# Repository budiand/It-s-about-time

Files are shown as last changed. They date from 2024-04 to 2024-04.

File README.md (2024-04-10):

# Proiect - It's about time!

## Realizare schematic:

Cu ajutorul fișierului [hector_watch.pdf](https://ocw.cs.pub.ro/courses/_media/tsc/hector_watch.pdf) ce conține indicații, a fost realizat schematic-ul. Deoarece butoanele și conectorul LCD din biblioteca de mai sus nu respectă anumite criterii, a fost necesară desenarea footprint-urilor acestora și atașarea într-o nouă bibliotecă. Corectitudinea a fost verificată folosind ERC.

## Realizare board:

Primul pas a fost decuparea PCB-ului, astfel încât acesta să respecte indicațiile de măsură (diam = 36mm). Primele componente așezate pe board au fost modulul ESP, conectorul USB C și butoanele, deoarece acestea sunt cele mai restrictive. Așezarea celorlalte componente s-a realizat ținând cont de numărul de semnale din circuit, astfel că numărul cel mai mare de semnale a avut prioritate. Traseele au fost rutate astfel încât să se respecte anumite constrângeri și reguli de "good practice" precum: evitarea intersectării traseelor, evitarea unghiurilor drepte, și altele. În final a fost realizată verificarea DRC cu succes.

## Probleme întâmpinate:

- Din cauza numărului mare de componente și a spațiului restrâns, au fost necesare mai multe încercări pentru a realiza o așezare optimă a componentelor.
- Realizarea footprint-urilor pentru butoane și pentru conectorul LCD a fost dificilă, deoarece a necesitat măsurători precise și ajustări.

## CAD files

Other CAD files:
Hector_Watch.f3z

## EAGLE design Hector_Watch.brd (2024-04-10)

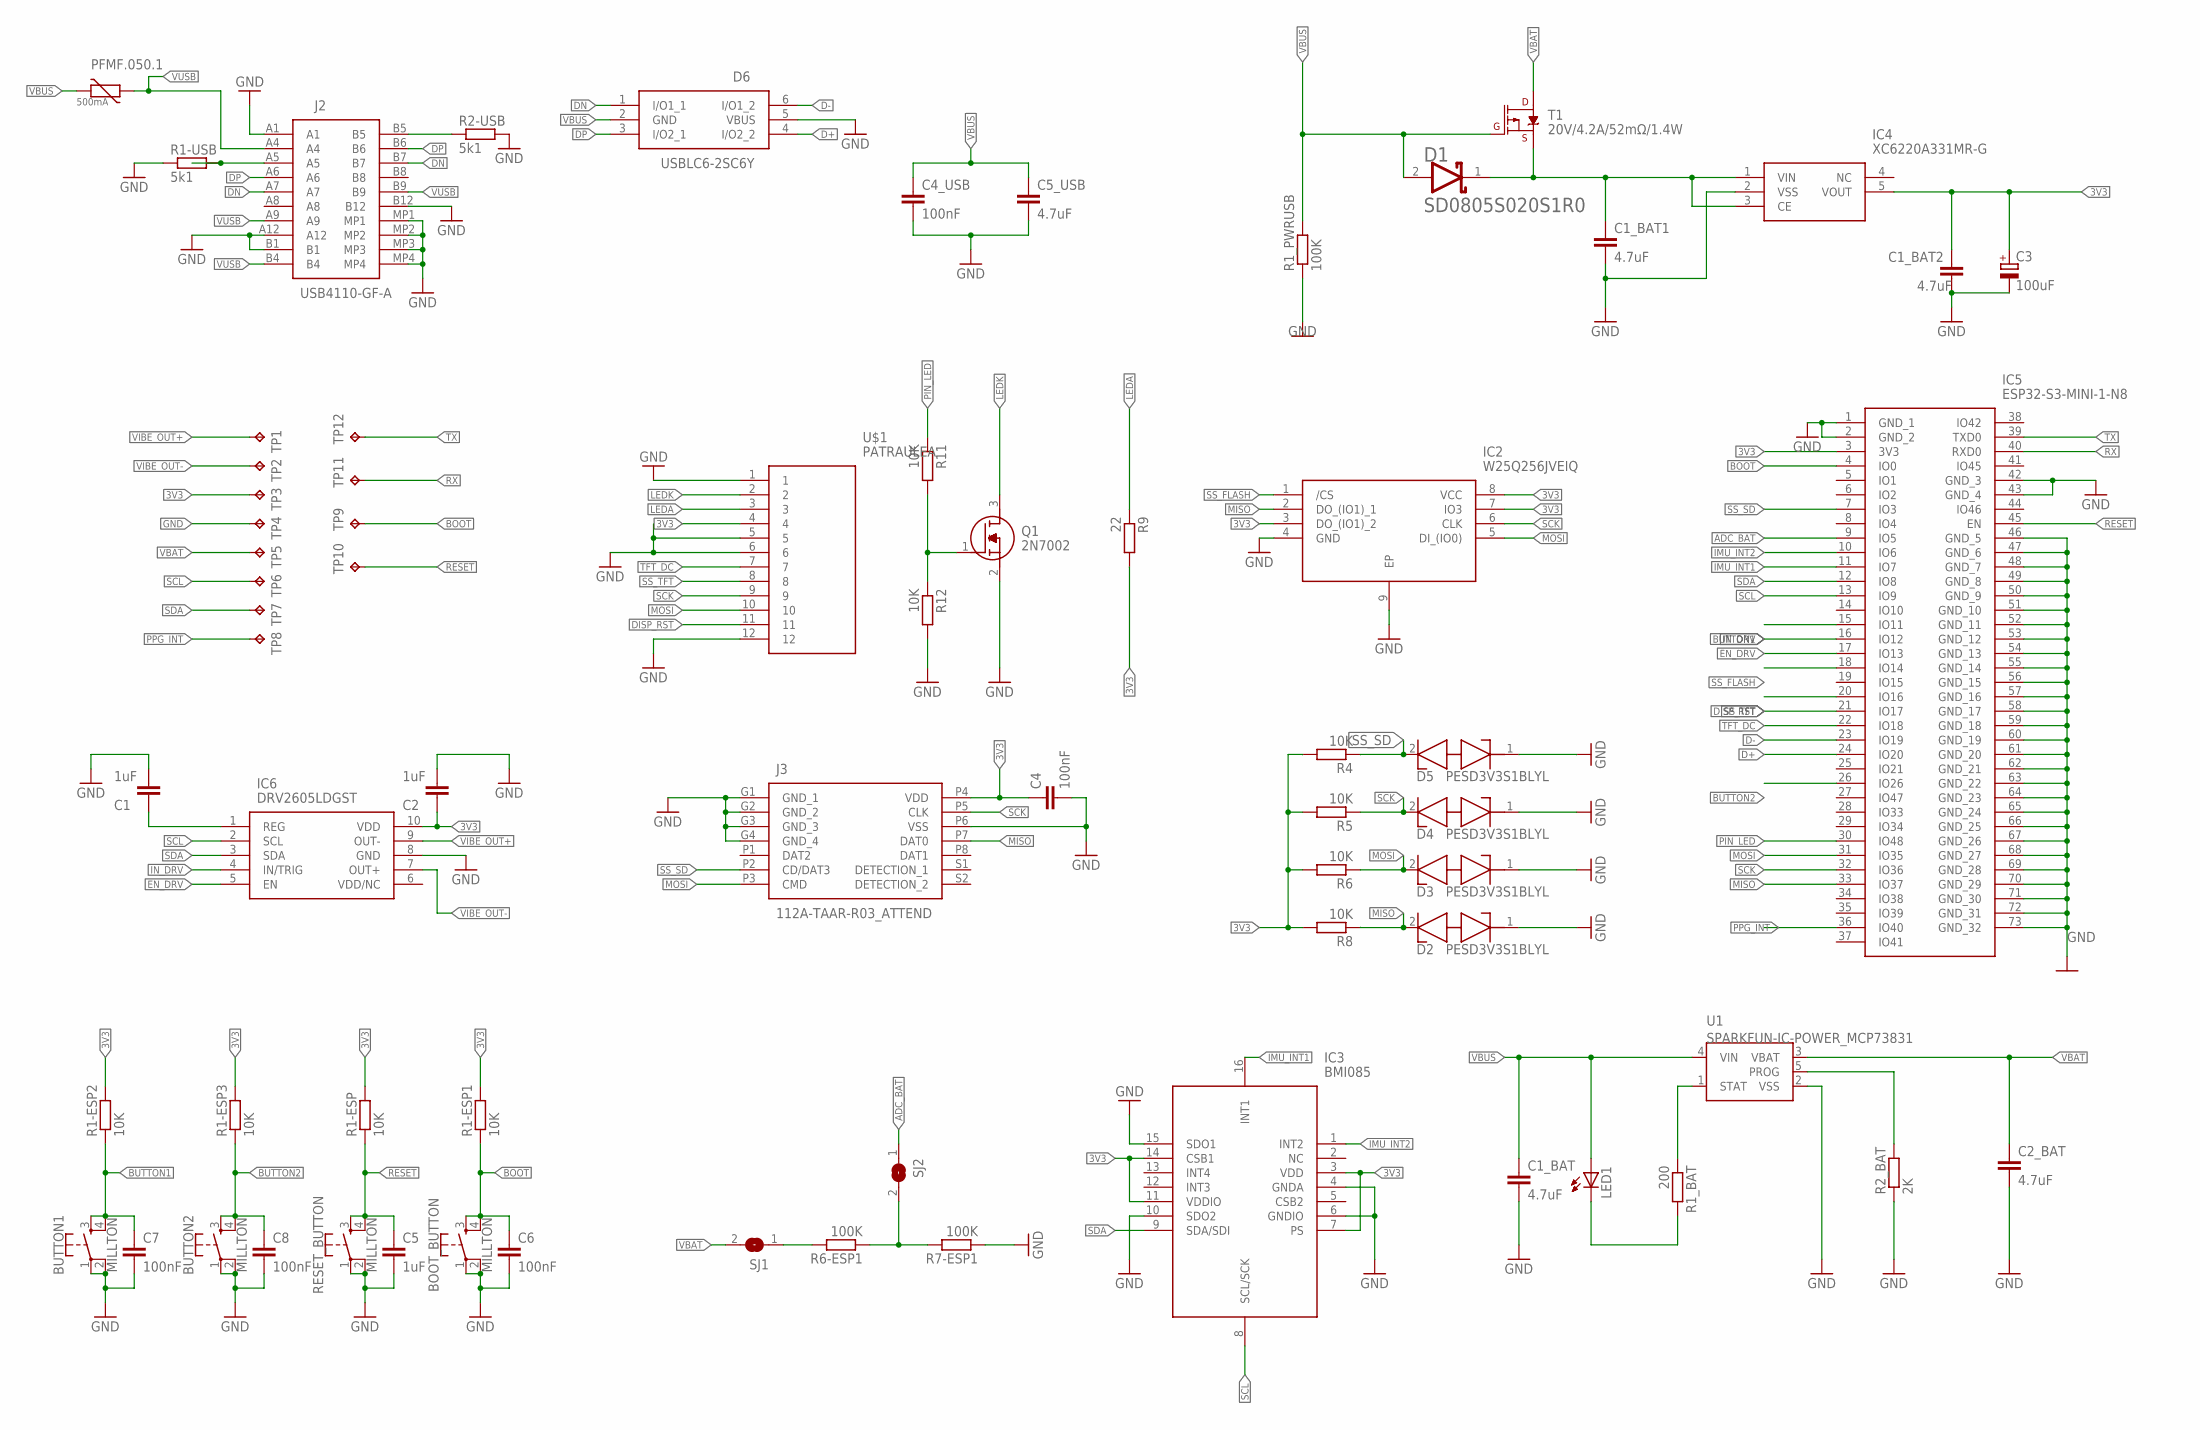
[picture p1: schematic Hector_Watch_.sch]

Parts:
BOOT_BUTTON: MILLTON
BUTTON1, BUTTON2: MILLTON
C1, C2, C5: 1uF; EAGLE-LTSPICE_C0402
C1_BAT, C1_BAT1, C1_BAT2, C2_BAT, C5_USB: 4.7uF; RCL_C0603
C3: 100uF; CT3528
C4, C6, C7, C8: 100nF; EAGLE-LTSPICE_C0402
C4_USB: 100nF; RCL_C0603
D1: AVX---SD0805S020S1R0_AVX_SD0805S020S1R0AVX_SD0805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; AVX---SD0805S020S1R0_AVX_SD0805S020S1R0_0
D2, D3, D4, D5: PESD3V3S1BLYL; PESD5V0S1BL315
D6: USBLC6-2SC6Y; SOT95P280X145-6N
IC2: W25Q256JVEIQ; SON127P800X600X80-9N
IC3: BMI085
IC4: XC6220A331MR-G; SOT95P280X120-5N
IC5: ESP32-S3-MINI-1-N8; ESP32S3MINI1N8
IC6: DRV2605LDGST; SOP50P490X110-10N
J2: USB4110-GF-A; USB4110GFA
J3: 112A-TAAR-R03_ATTEND; 112ATAARR03ATTEND
LED1: ADAFRUIT_LEDCHIP-LED0603; ADAFRUIT_CHIP-LED0603
PFMF.050.1: VARISTOR_VARISTORCN1812; VARISTOR_CT/CN1812
Q1: 2N7002; SOT96P240X120-3N
R1-ESP, R1-ESP1, R1-ESP2, R1-ESP3, R4, R5, R6, R8, R11, R12: 10K; EAGLE-LTSPICE_R0402
R1-USB, R2-USB: 5k1; EAGLE-LTSPICE_R0402
R1_BAT: 200; EAGLE-LTSPICE_R0402
R1_PWRUSB, R6-ESP1, R7-ESP1: 100K; EAGLE-LTSPICE_R0402
R2_BAT: 2K; EAGLE-LTSPICE_R0402
R9: 22; EAGLE-LTSPICE_R0402
RESET_BUTTON: MILLTON
SJ1, SJ2: SJ
T1: 20V/4.2A/52mΩ/1.4W; SPARKFUN-DISCRETESEMI_SOT23-3
TP1, TP2, TP3, TP4, TP5, TP6, TP7, TP8, TP9, TP10, TP11, TP12: TPTP20R; TP20R
U1: SPARKFUN-IC-POWER_MCP73831; SPARKFUN-IC-POWER_SOT23-5
U$1: PATRAULEA; PCA6LA12HL3TR

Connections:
3V3: C1_BAT2.1, C2.2, C3.+, C4.1, IC2.3 (DO_(IO1)_2), IC2.7 (IO3), IC2.8 (VCC), IC3.3 (VDD), IC3.7 (PS), IC3.11 (VDDIO), IC3.14 (CSB1), IC4.5 (VOUT), IC5.3 (3V3), IC6.10 (VDD), J3.P4 (VDD), R1-ESP.2, R1-ESP1.2, R1-ESP2.2, R1-ESP3.2, R4.2, R5.2, R6.2, R8.2, R9.2, TP3.TP, U$1.4
ADC_BAT: IC5.9 (IO5), SJ2.1
BOOT: BOOT_BUTTON.3, BOOT_BUTTON.4, C6.1, IC5.4 (IO0), R1-ESP1.1, TP9.TP
BUTTON1: BUTTON1.3, BUTTON1.4, C7.1, IC5.15 (IO11), R1-ESP2.1
BUTTON2: BUTTON2.3, BUTTON2.4, C8.1, IC5.26 (IO26), R1-ESP3.1
D+: D6.4 (I/O2_2), IC5.24 (IO20)
D-: D6.6 (I/O1_2), IC5.23 (IO19)
DISP_RST: IC5.20 (IO16), U$1.11
DN: D6.1 (I/O1_1), J2.A7, J2.B7
DP: D6.3 (I/O2_1), J2.A6, J2.B6
EN_DRV: IC5.17 (IO13), IC6.5 (EN)
GND: BOOT_BUTTON.1, BOOT_BUTTON.2, BUTTON1.1, BUTTON1.2, BUTTON2.1, BUTTON2.2, C1.1, C1_BAT.2, C1_BAT1.2, C1_BAT2.2, C2.1, C2_BAT.2, C3.-, C4.2, C4_USB.2, C5.2, C5_USB.2, C6.2, C7.2, C8.2, D2.1 (K1), D3.1 (K1), D4.1 (K1), D5.1 (K1), D6.5 (VBUS), IC2.4 (GND), IC2.9 (EP), IC3.4 (GNDA), IC3.6 (GNDIO), IC3.10 (SDO2), IC3.15 (SDO1), IC4.2 (VSS), IC5.1 (GND_1), IC5.2 (GND_2), IC5.42 (GND_3), IC5.43 (GND_4), IC5.46 (GND_5), IC5.47 (GND_6), IC5.48 (GND_7), IC5.49 (GND_8), IC5.50 (GND_9), IC5.51 (GND_10), IC5.52 (GND_11), IC5.53 (GND_12), IC5.54 (GND_13), IC5.55 (GND_14), IC5.56 (GND_15), IC5.57 (GND_16), IC5.58 (GND_17), IC5.59 (GND_18), IC5.60 (GND_19), IC5.61 (GND_20), IC5.62 (GND_21), IC5.63 (GND_22), IC5.64 (GND_23), IC5.65 (GND_24), IC5.66 (GND_25), IC5.67 (GND_26), IC5.68 (GND_27), IC5.69 (GND_28), IC5.70 (GND_29), IC5.71 (GND_30), IC5.72 (GND_31), IC5.73 (GND_32), IC6.8 (GND), J2.A1, J2.A12, J2.B1, J2.B12, J2.MP1, J2.MP2, J2.MP3, J2.MP4, J3.G1 (GND_1), J3.G2 (GND_2), J3.G3 (GND_3), J3.G4 (GND_4), J3.P6 (VSS), Q1.2 (S), R1-USB.1, R1_PWRUSB.1, R2-USB.2, R2_BAT.1, R7-ESP1.1, R12.2, RESET_BUTTON.1, RESET_BUTTON.2, TP4.TP, U1.2 (VSS), U$1.1, U$1.5, U$1.6
IMU_INT1: IC3.16 (INT1), IC5.11 (IO7)
IMU_INT2: IC3.1 (INT2), IC5.10 (IO6)
IN_DRV: IC5.16 (IO12), IC6.4 (IN/TRIG)
LEDA: R9.1, U$1.3
LEDK: Q1.3 (D), U$1.2
MISO: D2.2 (K2), IC2.2 (DO_(IO1)_1), IC5.33 (IO37), J3.P7 (DAT0), R8.1
MOSI: D3.2 (K2), IC2.5 (DI_(IO0)), IC5.31 (IO35), J3.P3 (CMD), R6.1, U$1.10
unnamed: Q1.1 (G), R11.2, R12.1
unnamed: C1.2, IC6.1 (REG)
unnamed: J2.A5, R1-USB.2
unnamed: R6-ESP1.1, R7-ESP1.2, SJ2.2
unnamed: C1_BAT1.1, D1.1 (CATHODE), IC4.1 (VIN), IC4.3 (CE), T1.2 (S)
unnamed: R6-ESP1.2, SJ1.1
unnamed: LED1.C, R1_BAT.2
unnamed: R2_BAT.2, U1.5 (PROG)
unnamed: J2.B5, R2-USB.1
unnamed: R1_BAT.1, U1.1 (STAT)
PIN_LED: IC5.30 (IO48), R11.1
PPG_INT: IC5.36 (IO40), TP8.TP
RESET: C5.1, IC5.45 (EN), R1-ESP.1, RESET_BUTTON.3, RESET_BUTTON.4, TP10.TP
RX: IC5.40 (RXD0), TP11.TP
SCK: D4.2 (K2), IC2.6 (CLK), IC5.32 (IO36), J3.P5 (CLK), R5.1, U$1.9
SCL: IC3.8 (SCL/SCK), IC5.13 (IO9), IC6.2 (SCL), TP6.TP
SDA: IC3.9 (SDA/SDI), IC5.12 (IO8), IC6.3 (SDA), TP7.TP
SS_FLASH: IC2.1 (/CS), IC5.18 (IO14)
SS_SD: D5.2 (K2), IC5.7 (IO3), J3.P2 (CD/DAT3), R4.1
SS_TFT: IC5.21 (IO17), U$1.8
TFT_DC: IC5.22 (IO18), U$1.7
TX: IC5.39 (TXD0), TP12.TP
VBAT: C2_BAT.1, SJ1.2, T1.3 (D), TP5.TP, U1.3 (VBAT)
VBUS: C1_BAT.1, C4_USB.1, C5_USB.1, D1.2 (ANODE), D6.2 (GND), LED1.A, PFMF.050.1.2, R1_PWRUSB.2, T1.1 (G), U1.4 (VIN)
VIBE_OUT+: IC6.9 (OUT-), TP1.TP
VIBE_OUT-: IC6.7 (OUT+), TP2.TP
VUSB: J2.A4, J2.A9, J2.B4, J2.B9, PFMF.050.1.1

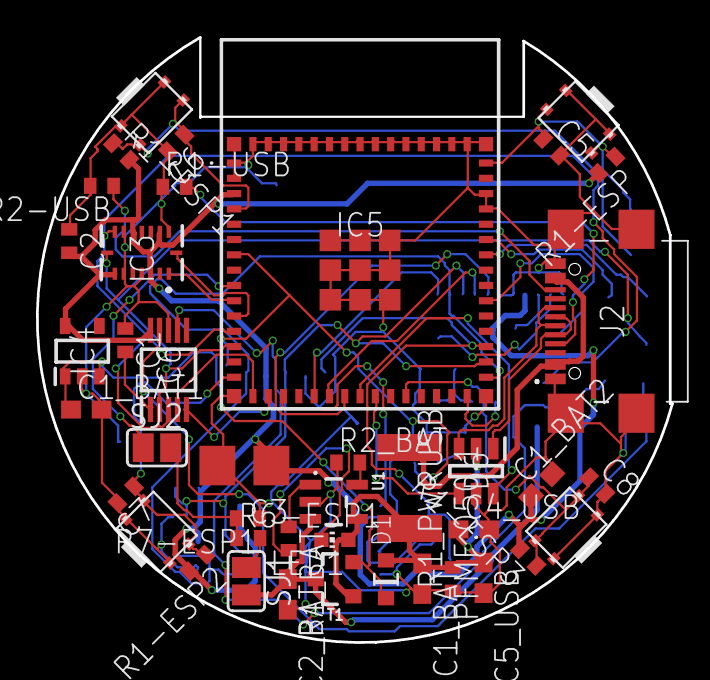
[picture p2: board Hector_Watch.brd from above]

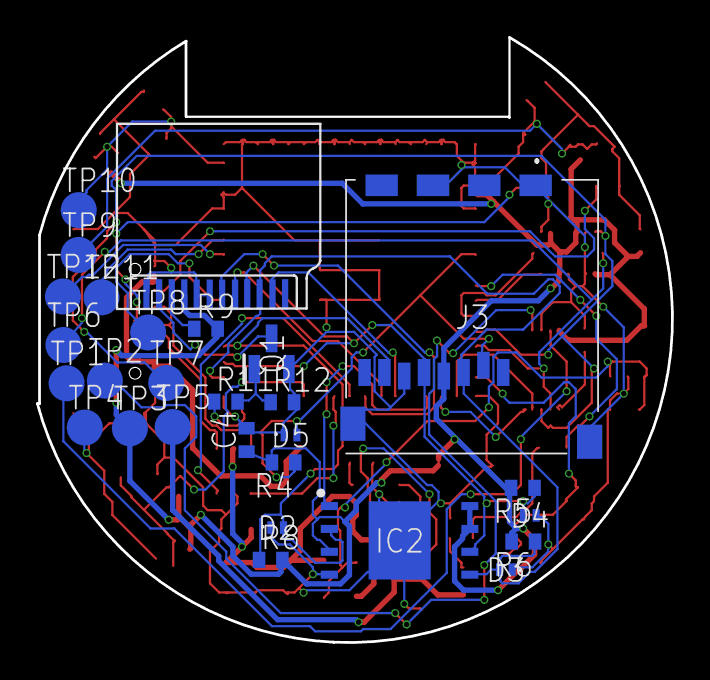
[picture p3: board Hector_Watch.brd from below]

Board: 2 copper layers, 35.3 x 33.6 mm, 69 parts (28 on the bottom side), 46 nets.
